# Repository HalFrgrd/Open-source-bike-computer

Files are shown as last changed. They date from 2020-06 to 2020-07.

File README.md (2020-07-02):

# Open source-bike-computer
Designs for an open source bike computer.

Similar projects:
- https://github.com/vincent290587/stravaV10
- http://opencyclingcomputer.eu/
- https://gitlab.com/PrzemoF/Open-Cycling-Computer
- https://github.com/hishizuka/pizero_bikecomputer

## BOM

<!-- ![t-call 1.3 dimensions](tcall_dimensions.png) -->
<!-- |---|---|---|---|---| -->
<!-- |**Preassembled** T-Call v1.3 TTGO ESP32 (no GPS)   | 29 x 7 x 8mm   | $16  | No  |   | -->

||**Item** | **Dimensions** | **Cost**  | **Using**  | |
|---|---|---|---|---|---|
|**Display**|
|| | | $13 | Yes  | |
|**Battery and charging**|
||3.7v Lithium Polymer 3200mAh | 50 x 75 x 7mm  | $8.50  | Yes  | |
||Receiver pad | 0.5mm thick  | $3  | Yes  | |
||Charging base  |  | $4  | Yes  | |
| **Storage** |
||16gb micro SD card | | $5  | Yes | |
|**Microcontroller and modules** |
||  ESP32 with LiPo charging  | | $5  | Yes  | |
|| nrf52840| |$5| Yes||
||  GPS module | | $5  | Yes  | |
||  SIM800L module | | $4  | Yes  | |
|| Micro SD card module  | | $1  | Yes  | |
|**Case**|
|| Glass screen protector | | $2 | Yes | |
|| 3D printed enclosure | |  | Yes | |
|| Glue | |  | Yes | |
|| 4 mounting screws | |  | Yes | |
|| 4 threaded heat inserts | |  | Yes | |
|| Rubber o-ring cabling | |  | Yes | |
| **Total** | | | | |

### Actually buying:

[LS027B7DH01](https://www.aliexpress.com/item/33020027250.html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,searchweb201602_,searchweb201603_)
The A indicates maximum of two bright pixels. 
Need an FPC 10 pin connector

## Design

3D printed

The buttons are capacitive pads. 
These pads will be a separate PCB that you can glue onto the 3D printed case.
This will be a water proof seal.
Will the capacitive pads be sensitive to rain?

Maximum target dimensions: 55 wide, 80 long, 20 high 

Need the on off control and charging port to be water proof.

### Capacitive buttons:
ESP32 has 10 capacitive-sensing GPIOs. 
So you don't need to include any extra components to use capacitive buttons
The nrf52 series also don't require any external componenents.

The capacitive pads could perhaps also go under the screen protector.
I'm guessing a screen protector wouldn't reduce the touch sensitivity that much.
This would serve as protection for the capacitive pads.

It is important to reduce the parasitic capacitance and increase the touch capacitance.
How to optimize: reduce trace length by optimizing PCB layout; reduce thickness of the overlay; enlarge electrode's area. 
Could have surface mount pins to reach PCB below.

https://github.com/espressif/esp-iot-solution/blob/master/documents/touch_pad_solution/touch_sensor_design_en.md

https://www.embedded.com/making-capacitive-touch-sensors-water-tolerant/

https://devzone.nordicsemi.com/nordic/short-range-guides/b/design-examples/posts/capacitive-touch-on-the-nrf52-series
### Firmware
https://www.youtube.com/watch?v=lQ157ftTnSs

Google maps platform has a $200 free monthly usage. Could use their route planning.

### Display
[2.42" OLED](https://www.aliexpress.com/item/32950562791.html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,searchweb201602_,searchweb201603_)
Not the best choice since they compete with sunlight.

Reflective LCD

https://www.buydisplay.com/blog/what-are-the-main-differences-between-LCD-and-OLED.html

https://www.buydisplay.com/3-4-inch-graphic-touchscreen-lcd-cog-module-240x160-single-sided-fpc
https://www.buydisplay.com/3-inch-touch-240x120-graphic-displays-lcd-serial-interface-black-on-white

https://forum.arduino.cc/index.php?topic=188040.0
https://forum.arduino.cc/index.php?topic=488097.0
https://forum.arduino.cc/index.php?topic=554754.0

Vincent's stravaV10 uses Memory LCD LS027B7DH01
https://makerdyne.com/2015/02/08/large-memory-lcd-breakout-board-details/
https://makerdyne.files.wordpress.com/2015/12/MemoryLCD_Breakout_Board_Schematic.pdf

The LS027B7DH01 with a backlight by Flex:
https://www.digikey.com/products/en?mpart=11103-06_T5&v=2004

### Wireless charging
This both for convenience and keeping the enclosure waterproof. 
Quite cheap for a whole setup. The pad inside of the computer can be very slim.

This one is small enough to be away from antennas.
https://www.mouser.co.uk/ProductDetail/PulseLarsen-Antennas/WMRR124F-2?qs=w%2Fv1CP2dgqrPY4DsgoYlEg%3D%3D

### Contactless payment
https://www.instructables.com/id/RFID-NFC-Tap-and-Go-Ring-for-Credit-Card-Payment/

Could just have a thin slot for a pay as you go card (Revolut or Monzo).Could have SMS notifications so that the bike computer knows when you have paid. 
Set up that sim with that bank card.
Could acetone the bank card to make it slimmer.

### SIM
https://lastminuteengineers.com/sim800l-gsm-module-arduino-tutorial/
I hope to be able to use the microphone pins to play pre-recorded messages.

### PCB design

Pin choice: It seems like the nrf52840 are pretty multi-purpose. For high-frequency stuff, try and avoid pins close to the antenna to avoid interference.
https://devzone.nordicsemi.com/f/nordic-q-a/52857/recommended-pin-usage

P0.0 = 0, P0.1 = 1 .... P0.31 = 31 P1.0 = 32, P1.1 = 33. 

Sharp memory schematics:
https://makerdyne.files.wordpress.com/2015/12/MemoryLCD_Breakout_Board_Schematic.pdf

One set of SPI pins per peripheral: they might work at different speeds. And I think the asynchronous aspect would mean the LCD could be prioritized.

https://github.com/DF4IAH/HFT-Core-Module

Antenna:
SIM868 is L1 band.
Glonass L1: about 1602 MHz
GPS L1: 1575.42 MHz
Beidou: 1575.42 MHz (Possibly lower: 1561.098MHz?)

https://www.antenova.com/integration-hub/antenna-selection-tool/

Drawing antennas as part of the PCB seem like a bad idea. 
They take a lot of testing.

Mouser sells the SR4L049 (both left and right versions) for about 3 dollars. SR4L034 is very similar.

The M20057 and M20047 modules combine the SAW and antenna. Power consumption is about 2ma,

M20047 cost: 4.50 gbp from mouser and at digikey
B3913 cost: 1.62gbp 
SR4L034 cost: 1.44
LNA?:

I'm pretty sure it needs an LNA. So I'm going with 
https://www.u-blox.com/sites/default/files/NEO-8Q-NEO-M8-FW3_HIM_%28UBX-15029985%29.pdf

[Picking a saw filter from Mouser](https://www.mouser.com/pdfdocs/HowToChoosetheOptimalSAWFilter.pdf)

SAW filter: You want something in the middle of the frequencies, so 1588ish and that has a wide enough bandwidth to capture the signals.
Two come up: B3913 and B3413. The B4310 is used in the HFT-Core-Module.
B4310 is from 2015. The B3913 and B3413 are very similar but the B3413 is newer and has improved electrostatic discharge (ESD) robustness. [Qualcomm RF360 website SAW filters for GNSS](https://rffe.qualcomm.com/product/search/automotive/Filters%20for%20GNSS). B4310 doesn't have Beidou next to it on the website. 
I can't find the B3413 in stock, so I'm using the B3913 in stock at digi key.

#### Questions
- The wireless charging setup.
- Battery level indicator.
- Why polarized capacitor in decoupling?
- RF SYNC
- What about low noise ammplifer LNA?

### Case
**Two pcb design**
Have a pcb at the top. 
This has a cut out for the screen.
This top pcb has capacitive buttons.
On the underside of this top pcb, are an on off switch and maybe the usb port. Also could have pressure, temperature, humidity sensor as it should be on the outside? The traces are the link between the outside and the inside.
The 3D printed bottom port of the case could just be unibody.
There would be pcb to pcb connectors.
The top pcb would have surface mounted pins on the underside.
The bottom pcb would have the female connectors.
When you align the pins, the top pcb drops into the bottom one.
[These are pin and socket](https://blog.samtec.com/post/custom-connectors-for-stacking-pcbs/)
There would be o-rings around each of the mounting screws and o-ring cord going around the perimeter.

The two PCBs could fit together inside the 100x100mm size.

Could this extend the ground plane?:
https://blog.antenova.com/how-well-can-an-embedded-antenna-perform-on-a-tiny-pcb

Threaded PCB inserts could provide a flush mounting style.

Connections between plates:
- Ground
- VCC
- Battery switch
- Data+
- Data -
- 5x buttons
- Temperature, pressure, humidity sensor.

Connectors: https://www.samtec.com/products/ftsh

Pins:FTSH-104-01-F-DV
Connector: CLP-104-02-F-D

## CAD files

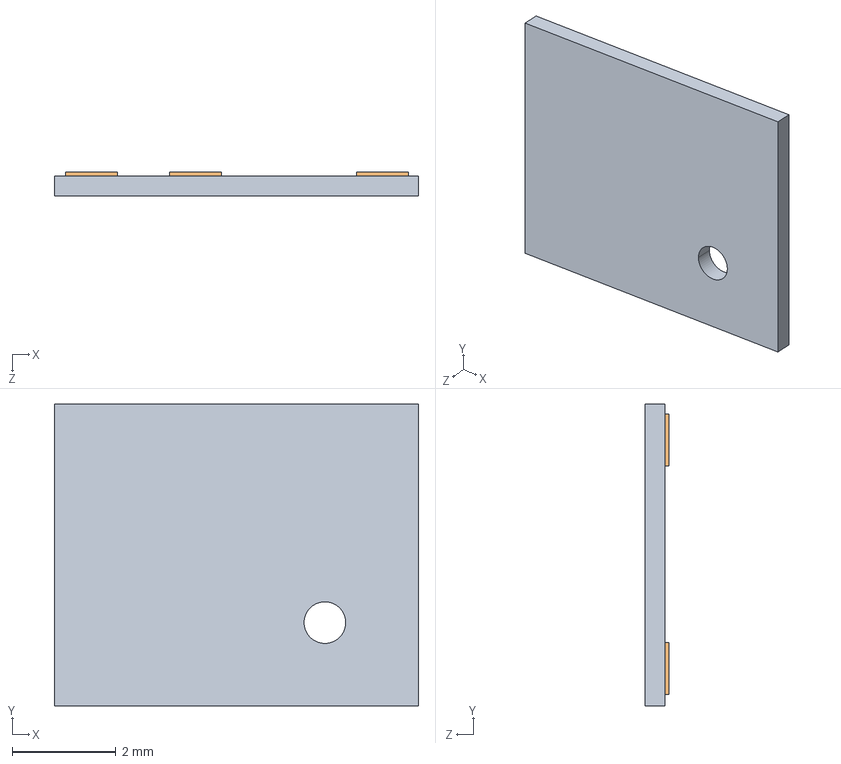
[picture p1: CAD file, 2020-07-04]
pcb/open_bike_comp3D/SR4G008_Sinica.STEP
7.00 x 5.80 x 0.469 mm
ant part with text and hole
pads

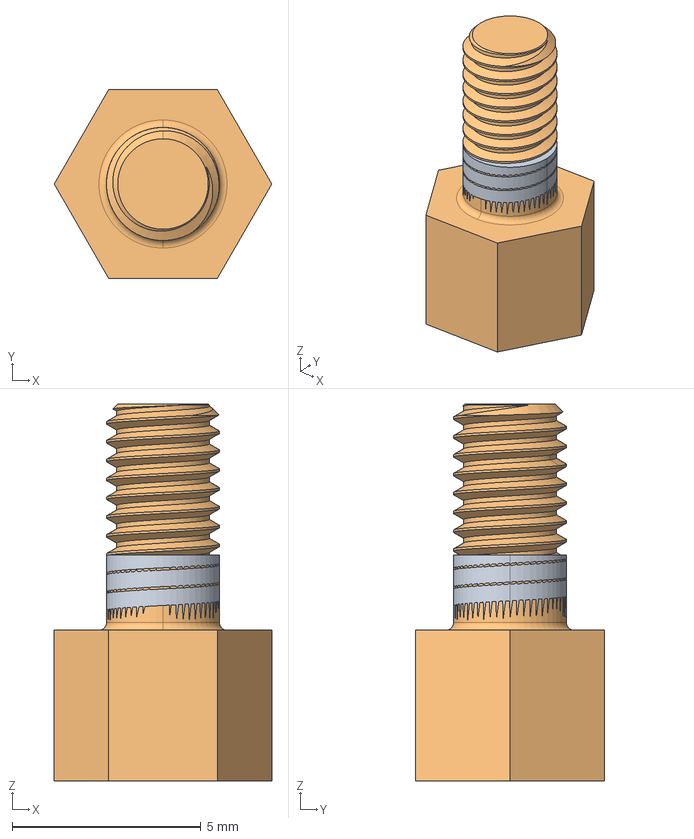
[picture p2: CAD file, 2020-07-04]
pcb/open_bike_comp3D/r30-3000402.stp
5.77 x 5.00 x 10.0 mm

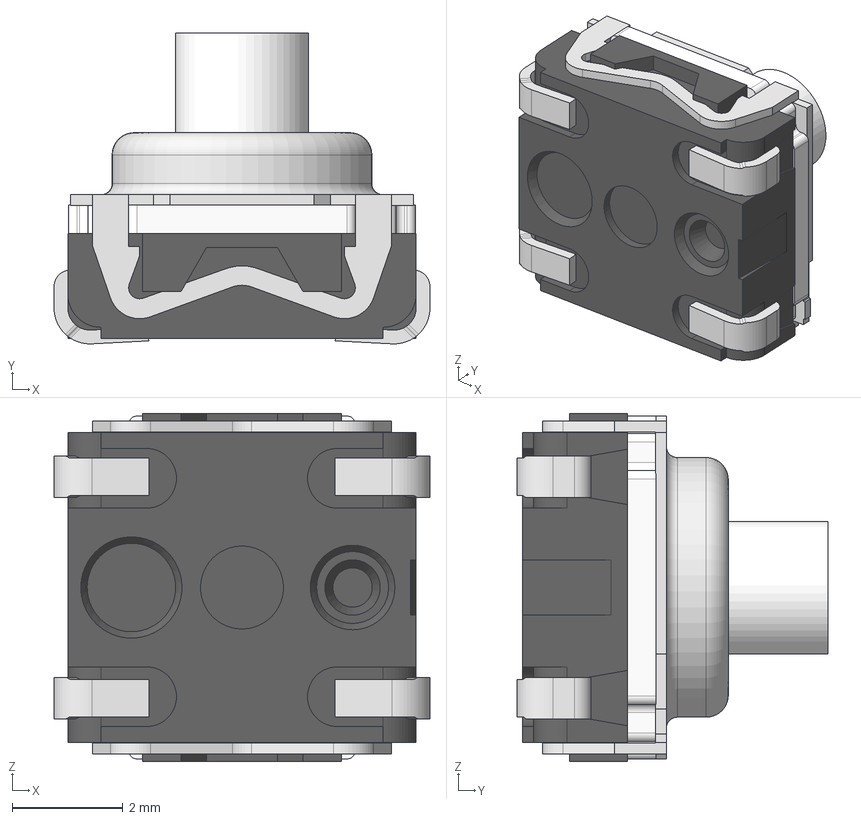
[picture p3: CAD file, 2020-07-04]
pcb/open_bike_comp3D/KSC521JROHS.stp
6.80 x 5.62 x 6.30 mm
_KSC5_body
_KSC5_button
_KSC5_cover
_KSC51J_pin x 4

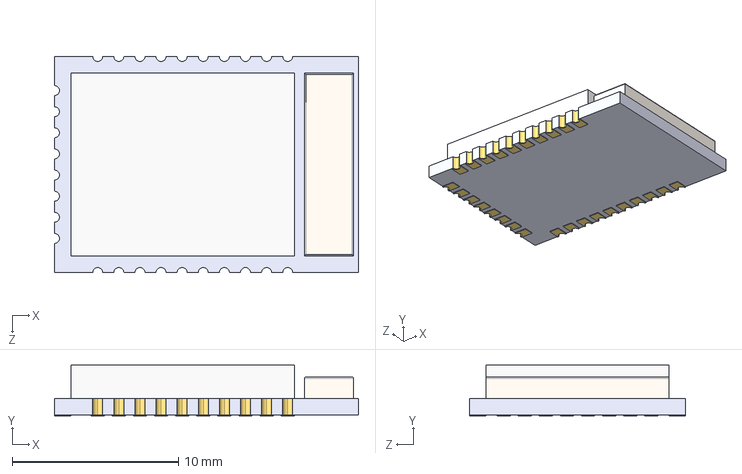
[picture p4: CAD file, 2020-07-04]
pcb/open_bike_comp3D/E73-2G4M08S1C.step
18.3 x 3.05 x 13.0 mm

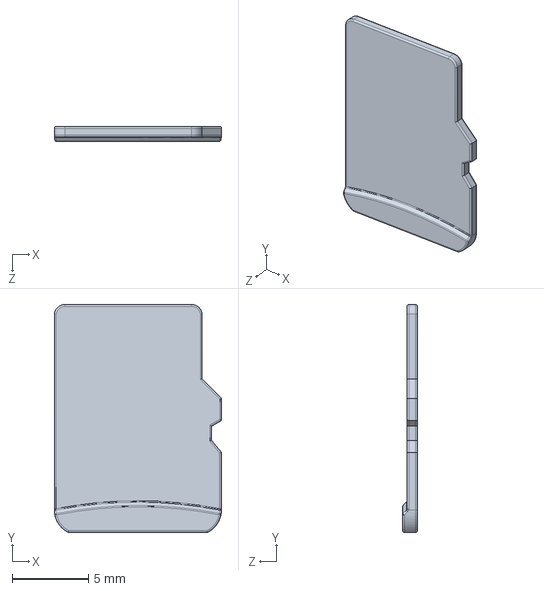
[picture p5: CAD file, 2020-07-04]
pcb/open_bike_comp3D/Micro SD Card.STEP
11.0 x 15.0 x 1.00 mm

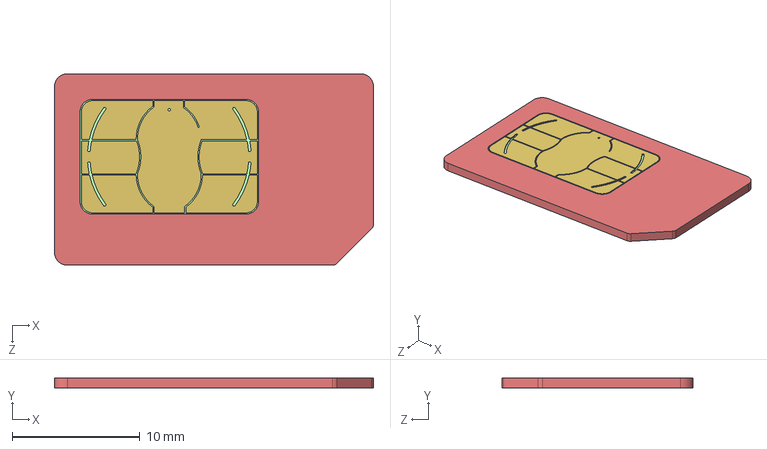
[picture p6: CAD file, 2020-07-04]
pcb/open_bike_comp3D/SIM card.STEP
25.0 x 0.8 x 15.0 mm

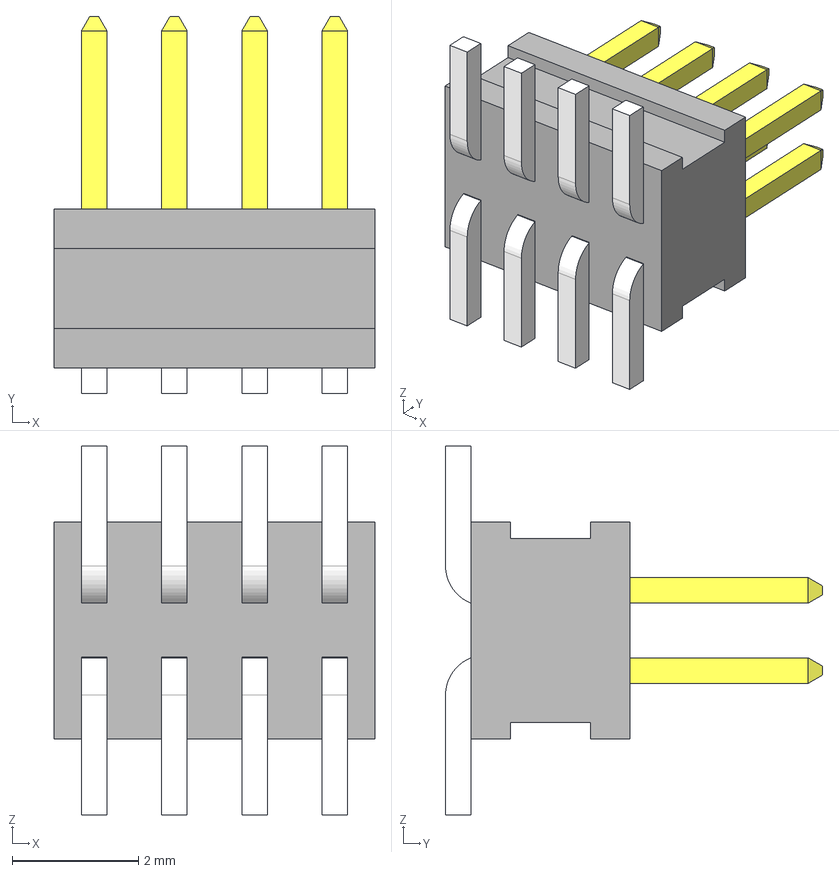
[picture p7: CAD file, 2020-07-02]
pcb/open_bike_comp3D/FTSH-104-01-F-DV.stp
5.08 x 5.97 x 5.84 mm
_FTSH-104-01-F-DV_body
_FTSH-104-01-F-DV_pins1
_FTSH-104-01-F-DV_pins2

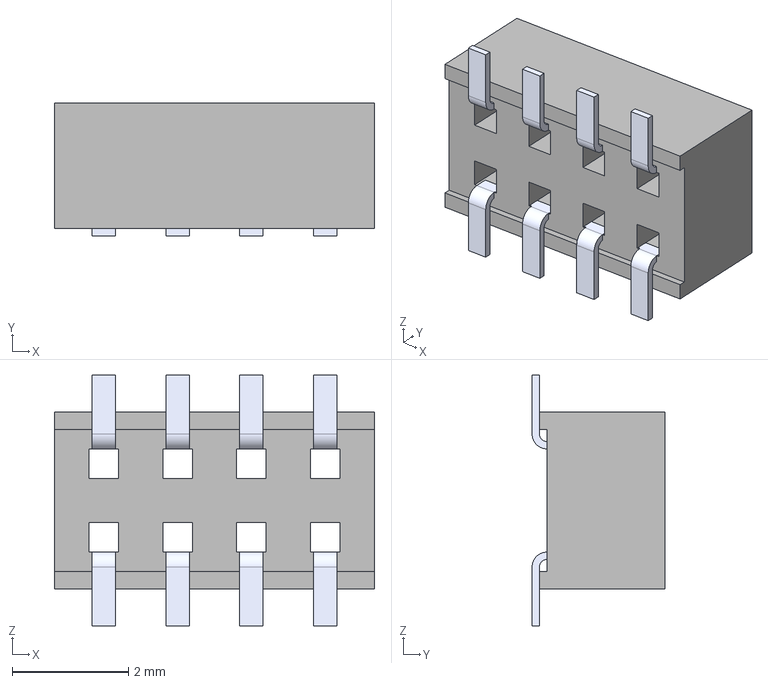
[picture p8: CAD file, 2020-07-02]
pcb/open_bike_comp3D/CLP-104-02-F-D.stp
5.51 x 2.29 x 4.32 mm
_CLP-104-2-F-D_terminal
_C-106-22-104_Pin x 2

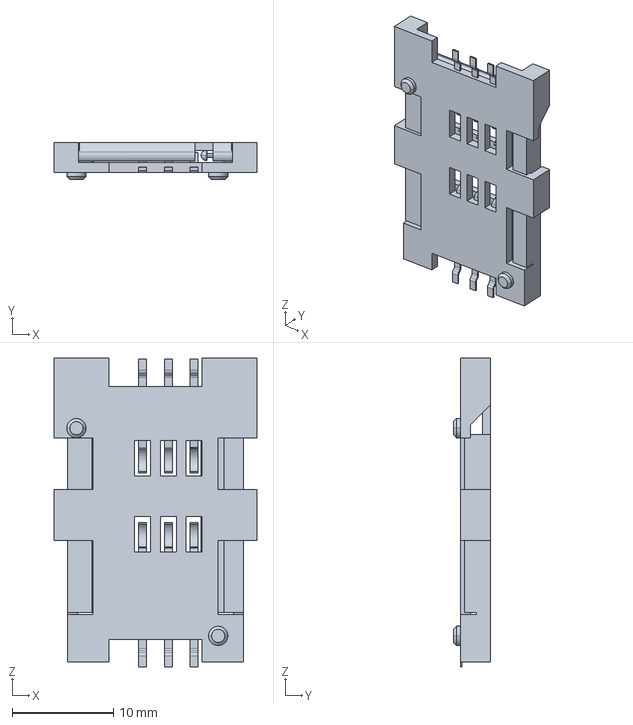
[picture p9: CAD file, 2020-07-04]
pcb/open_bike_comp3D/7312S0815X29LFC_sim_holder.stp
20.0 x 3.70 x 30.5 mm

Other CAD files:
case_design/case_design.FCStd

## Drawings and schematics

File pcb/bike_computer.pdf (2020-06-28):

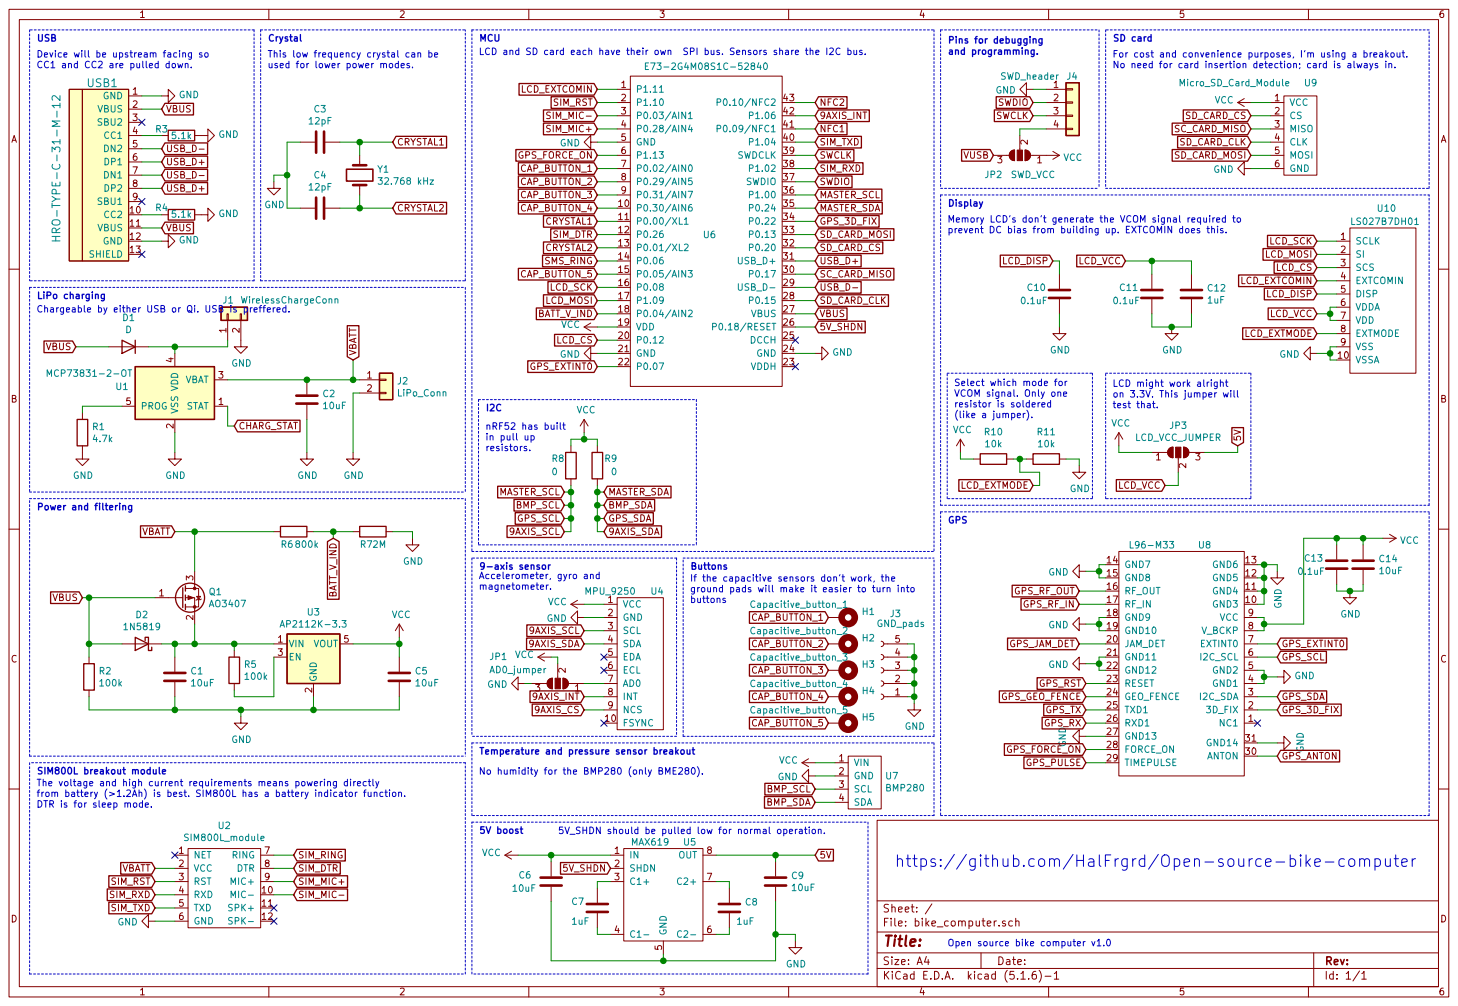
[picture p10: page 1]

CC1 and CC2 are pulled down.

This low frequency crystal can be
used for lower power modes.

For cost and convenience purposes, I'm using a breakout.
No need for card insertion detection; card is always in.

Display Memory LCD's don't generate the VCOM signal required to

prevent DC bias from building up. EXTCOMIN does this.

LiPo charging

Select which mode for VCOM signal. Only one resistor is soldered (like a jumper).

LCD might work alright

on 3.3V. This jumper will test that. 9-axis sensor
nRF52 has built
in pull up resistors. No humidity for the BMP280 (only BME280).

If the capacitive sensors don't work, the 5

Temperature and pressure sensor breakout

The voltage and high current requirements means powering directly
from battery (>1.2Ah) is best. SIM800L has a battery indicator function.
DTR is for sleep mode.

5V_SHDN should be pulled low for normal operation.

https://github.com/HalFrgrd/Open-source-bike-computer

Open source bike computer v1.0

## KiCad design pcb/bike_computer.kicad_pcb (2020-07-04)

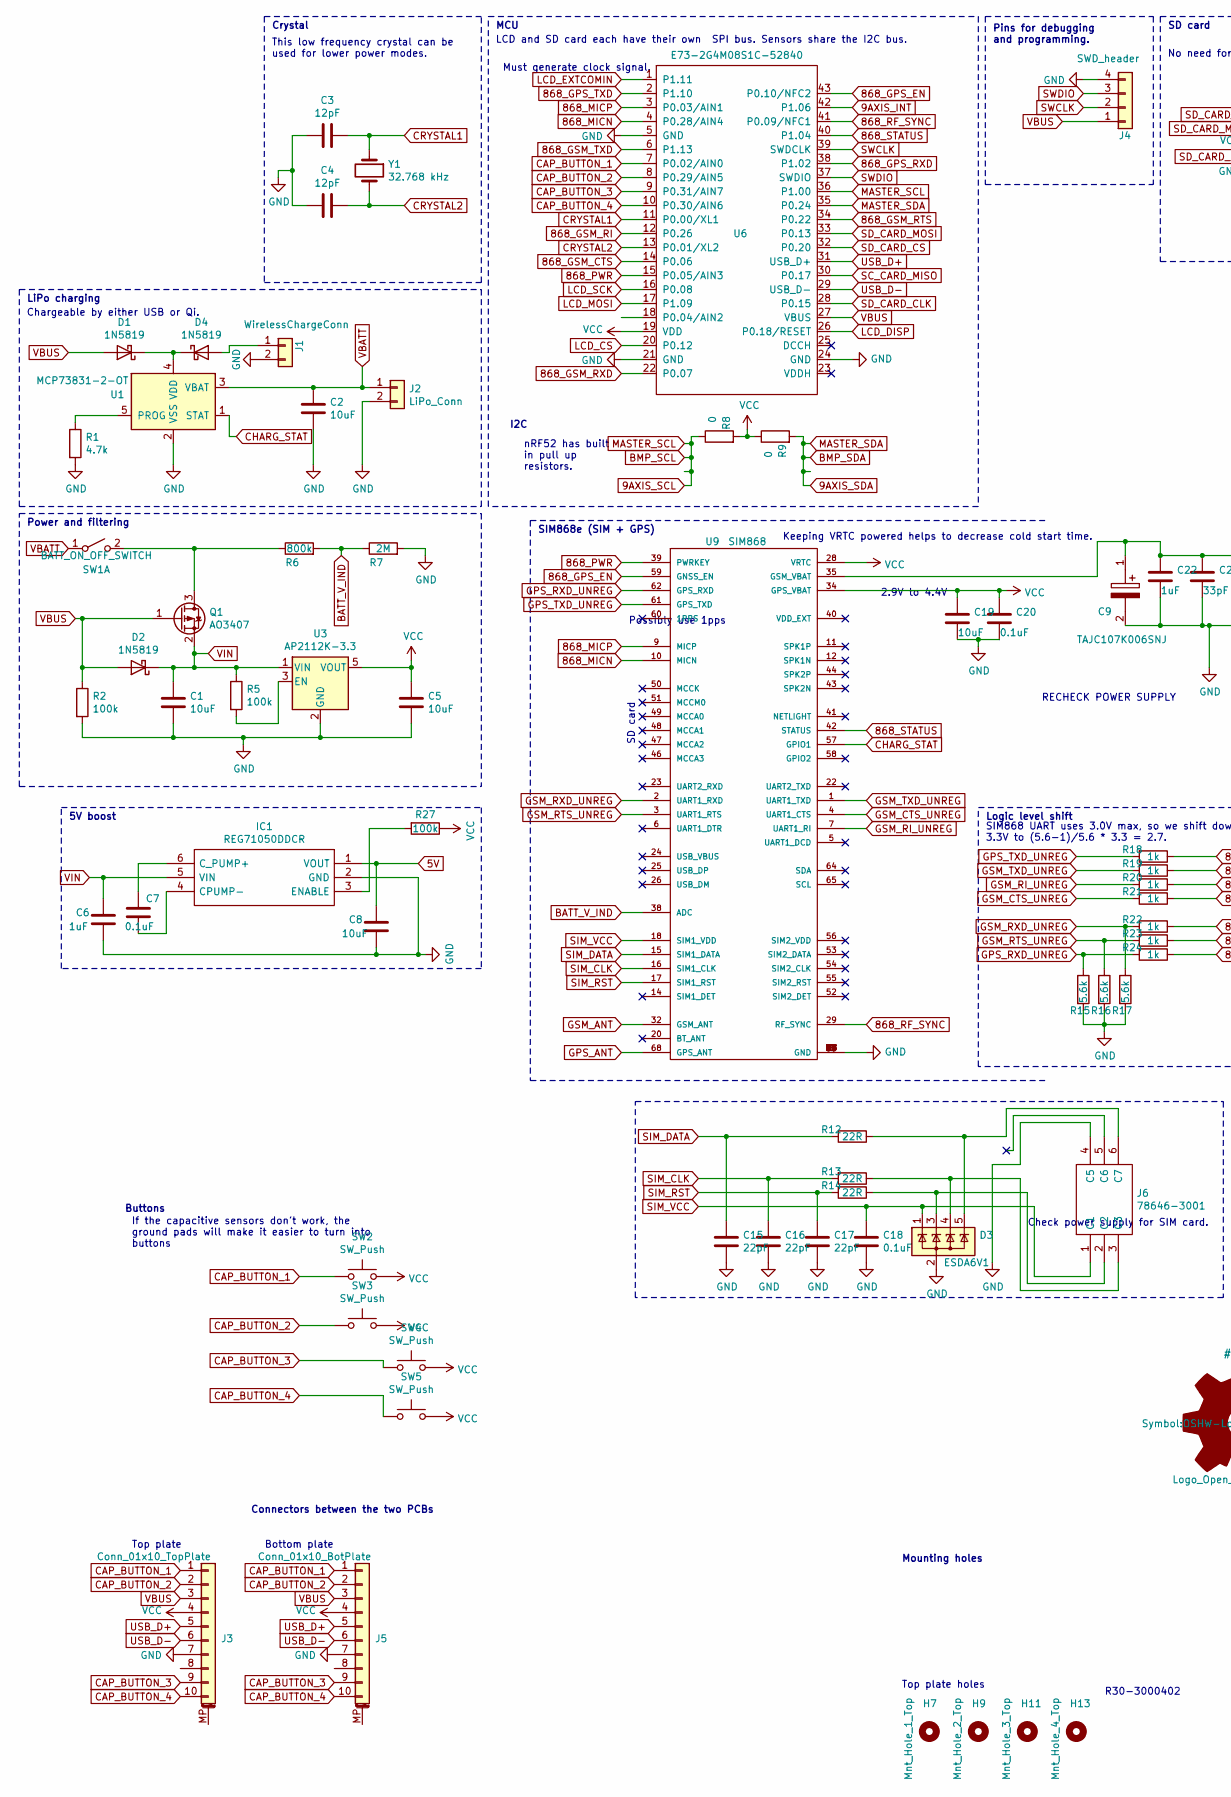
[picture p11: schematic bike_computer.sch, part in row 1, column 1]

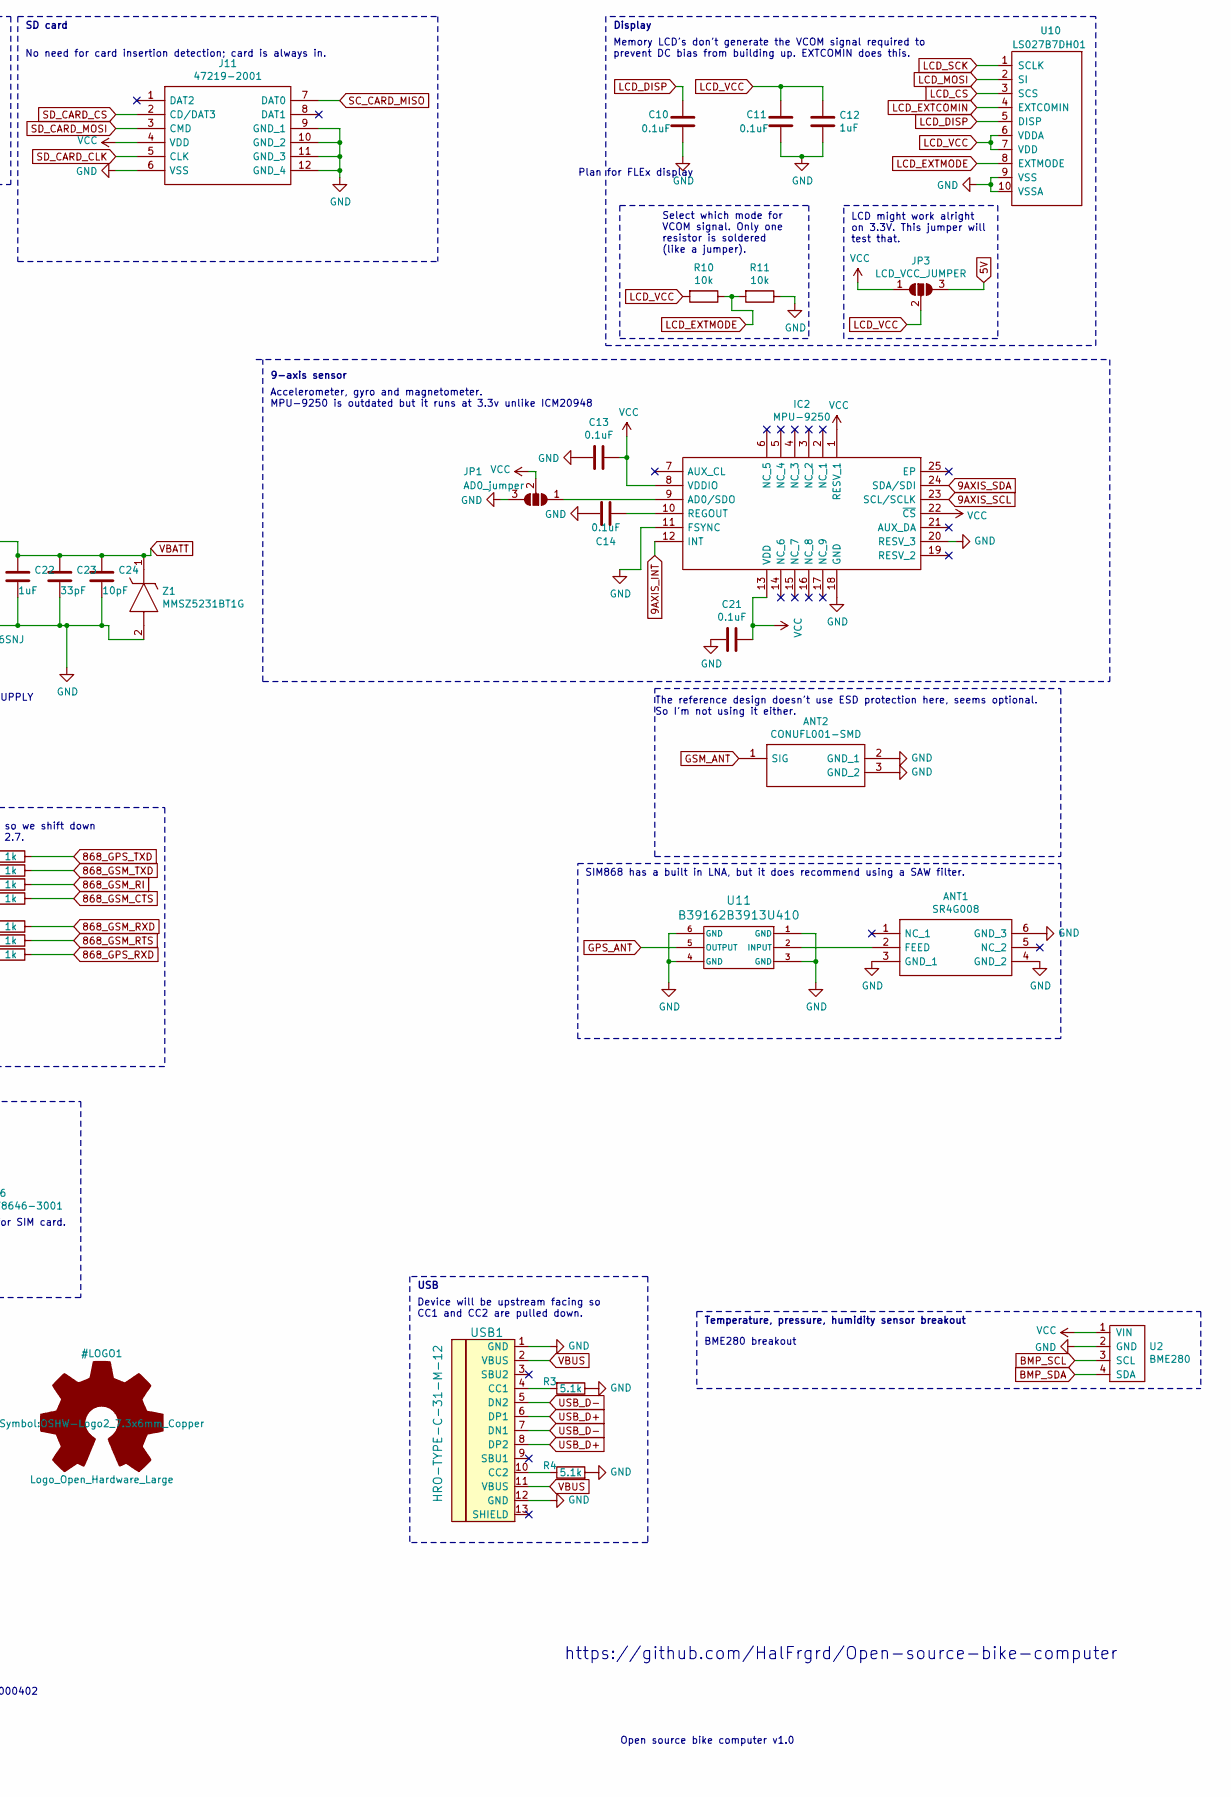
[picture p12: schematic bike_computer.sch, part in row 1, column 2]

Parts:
ANT1: SR4G008; Mouser Part Number 237-SR4G008
ANT2: CONUFL001-SMD; Mouser Part Number 712-CONUFL001-SMD
C1, C2, C5, C8, C19: 10uF; 1206_0603_hand_solder
C3, C4: 12pF; 1206_0603_hand_solder
C6, C12, C22: 1uF; 1206_0603_hand_solder
C7, C10, C11, C13, C14, C18, C20, C21: 0.1uF; 1206_0603_hand_solder
C9: TAJC107K006SNJ; CAPPM6032X280N; Mouser Part Number 581-TAJC107K006SNJ
C15, C16, C17: 22pF; 1206_0603_hand_solder
C23: 33pF; 1206_0603_hand_solder
C24: 10pF; 1206_0603_hand_solder
D1, D2, D4: 1N5819; D_SOD-123
D3: ESDA6V1; SOT95P280X145-6N
H7: Mnt_Hole_1_Top; R303000402
H9: Mnt_Hole_2_Top; R303000402
H11: Mnt_Hole_3_Top; R303000402
H13: Mnt_Hole_4_Top; R303000402
IC1: REG71050DDCR; SOT95P280X110-6N; Mouser Part Number 595-REG71050DDCR
IC2: MPU-9250; QFN40P300X300X105-25N-D; Mouser Part Number 410-MPU-9250
J1: WirelessChargeConn; PinHeader_1x02_P1.27mm_Vertical
J2: LiPo_Conn; PinHeader_1x02_P1.27mm_Vertical
J3: Conn_01x10_TopPlate; 10_smd_connector
J4: SWD_header; PinHeader_1x04_P2.54mm_Vertical
J5: Conn_01x10_BotPlate; PinHeader_1x10_P2.54mm_Vertical
J6: 78646-3001; Mouser Part Number 538-78646-3001
J11: 47219-2001; 472192001; Mouser Part Number 538-47219-2001
JP1: AD0_jumper; SolderJumper-3_P1.3mm_Open_RoundedPad1.0x1.5mm
JP3: LCD_VCC_JUMPER; SolderJumper-3_P1.3mm_Open_RoundedPad1.0x1.5mm
Q1: AO3407; SOT-23
R1: 4.7k; 1206_0603_hand_solder
R2, R5, R27: 100k; 1206_0603_hand_solder
R3, R4: 5.1k; 1206_0603_hand_solder
R6: 800k; 1206_0603_hand_solder
R7: 2M; 1206_0603_hand_solder
R8, R9: 0; 1206_0603_hand_solder
R10, R11: 10k; 1206_0603_hand_solder
R12, R13, R14: 22R; 1206_0603_hand_solder
R15, R16, R17: 5.6k; 1206_0603_hand_solder
R18, R19, R20, R21, R22, R23, R24: 1k; 1206_0603_hand_solder
SW1: BATT_ON_OFF_SWITCH; switch_MSK-12C02_smd
SW2, SW3, SW4, SW5: SW_Push; KSC521JROHS_with_pad
U1: MCP73831-2-OT; SOT-23-5
U2: BME280
U3: AP2112K-3.3; SOT-23-5
U6: E73-2G4M08S1C-52840
U9: SIM868; XCVR_SIM868
U10: LS027B7DH01; TE_1-1734839-0_1x10-1MP_P0.5mm_Horizontal
U11: B39162B3913U410
USB1: HRO-TYPE-C-31-M-12
Y1: 32.768 kHz; Crystal_DS26_D2.0mm_L6.0mm_Horizontal
Z1: MMSZ5231BT1G; SOD3716X135N; Mouser Part Number 863-MMSZ5231BT1G

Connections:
5V: C8.1, IC1.1 (VOUT), JP3.3 (B)
9AXIS_INT: IC2.12 (INT), U6.42 (P1.06)
9AXIS_SCL: IC2.23 (SCL/SCLK), R8.1, U2.3 (SCL), U6.36 (P1.00)
9AXIS_SDA: IC2.24 (SDA/SDI), R9.2, U2.4 (SDA), U6.35 (P0.24)
868_GPS_EN: U6.43 (P0.10/NFC2), U9.59 (GNSS_EN)
868_GPS_RXD: R24.1, U6.38 (P1.02)
868_GPS_TXD: R18.1, U6.2 (P1.10)
868_GSM_CTS: R21.1, U6.14 (P0.06)
868_GSM_RI: R20.1, U6.12 (P0.26)
868_GSM_RTS: R23.1, U6.34 (P0.22)
868_GSM_RXD: R22.1, U6.22 (P0.07)
868_GSM_TXD: R19.1, U6.6 (P1.13)
868_MICN: U6.4 (P0.28/AIN4), U9.10 (MICN)
868_MICP: U6.3 (P0.03/AIN1), U9.9 (MICP)
868_PWR: U6.15 (P0.05/AIN3), U9.39 (PWRKEY)
868_RF_SYNC: U6.41 (P0.09/NFC1), U9.29 (RF_SYNC)
868_STATUS: U6.40 (P1.04), U9.42 (STATUS)
BATT_V_IND: R6.2, R7.1, U9.38 (ADC)
CAP_BUTTON_1: J3.1, J5.1, SW2.1, U6.7 (P0.02/AIN0)
CAP_BUTTON_2: J3.2, J5.2, SW3.1, U6.8 (P0.29/AIN5)
CAP_BUTTON_3: J3.9, J5.9, SW4.1, U6.9 (P0.31/AIN7)
CAP_BUTTON_4: J3.10, J5.10, SW5.1, U6.10 (P0.30/AIN6)
CHARG_STAT: U1.1 (STAT), U9.57 (GPIO1)
CRYSTAL1: C3.1, U6.11 (P0.00/XL1), Y1.1
CRYSTAL2: C4.1, U6.13 (P0.01/XL2), Y1.2
GND: ANT1.3 (GND_1), ANT1.4 (GND_2), ANT1.6 (GND_3), ANT2.2 (GND_1), ANT2.3 (GND_2), C1.2, C2.2, C3.2, C4.2, C5.2, C6.2, C8.2, C9.2, C10.2, C11.2, C12.2, C13.2, C14.1, C15.2, C16.2, C17.2, C18.2, C19.2, C20.2, C21.2, C22.2, C23.2, C24.2, D3.2 (A), IC1.2 (GND), IC2.11 (FSYNC), IC2.18 (GND), IC2.20 (RESV_3), J1.2, J2.2, J3.7, J4.4, J5.7, J6.4 (C5), J11.6 (VSS), J11.9 (GND_1), J11.10 (GND_2), J11.11 (GND_3), J11.12 (GND_4), JP1.3 (B), R1.2, R2.2, R3.1, R4.2, R7.2, R11.1, R15.2, R16.2, R17.2, U1.2 (VSS), U2.2 (GND), U3.2 (GND), U6.5 (GND), U6.21 (GND), U6.24 (GND), U9.8 (GND), U9.13 (GND), U9.19 (GND), U9.21 (GND), U9.27 (GND), U9.30 (GND), U9.31 (GND), U9.33 (GND), U9.36 (GND), U9.37 (GND), U9.45 (GND), U9.63 (GND), U9.66 (GND), U9.67 (GND), U9.69 (GND), U9.70 (GND), U9.71 (GND), U9.72 (GND), U9.73 (GND), U9.74 (GND), U9.75 (GND), U9.76 (GND), U9.77 (GND), U10.9 (VSS), U10.10 (VSSA), U11.1 (GND), U11.3 (GND), U11.4 (GND), U11.6 (GND), USB1.1 (GND), USB1.12 (GND), Z1.2
GPS_ANT: U9.68 (GPS_ANT), U11.5 (OUTPUT)
GPS_RXD_UNREG: R15.1, R24.2, U9.62 (GPS_RXD)
GPS_TXD_UNREG: R18.2, U9.61 (GPS_TXD)
GSM_ANT: ANT2.1 (SIG), U9.32 (GSM_ANT)
GSM_CTS_UNREG: R21.2, U9.4 (UART1_CTS)
GSM_RI_UNREG: R20.2, U9.7 (UART1_RI)
GSM_RTS_UNREG: R16.1, R23.2, U9.3 (UART1_RTS)
GSM_RXD_UNREG: R17.1, R22.2, U9.2 (UART1_RXD)
GSM_TXD_UNREG: R19.2, U9.1 (UART1_TXD)
LCD_CS: U6.20 (P0.12), U10.3 (SCS)
LCD_DISP: C10.1, U6.26 (P0.18/RESET), U10.5 (DISP)
LCD_EXTCOMIN: U6.1 (P1.11), U10.4 (EXTCOMIN)
LCD_EXTMODE: R10.1, R11.2, U10.8 (EXTMODE)
LCD_MOSI: U6.17 (P1.09), U10.2 (SI)
LCD_SCK: U6.16 (P0.08), U10.1 (SCLK)
LCD_VCC: C11.1, C12.1, JP3.2 (C), R10.2, U10.6 (VDDA), U10.7 (VDD)
unnamed: ANT1.2 (FEED), U11.2 (INPUT)
unnamed: C7.1, IC1.6 (C_PUMP+)
unnamed: C7.2, IC1.4 (CPUMP-)
unnamed: C14.2, IC2.10 (REGOUT)
unnamed: D1.1 (K), D4.1 (K), U1.4 (VDD)
unnamed: D3.3 (K), J6.2 (C2), R14.1
unnamed: D3.4 (K), J6.3 (C3), R13.1
unnamed: D3.5 (K), J6.6 (C7), R12.1
unnamed: D4.2 (A), J1.1
unnamed: IC1.3 (ENABLE), R27.2
unnamed: IC2.9 (AD0/SDO), JP1.1 (A)
unnamed: Q1.3 (D), R6.1, SW1.2 (B)
unnamed: R1.1, U1.5 (PROG)
unnamed: R3.2, USB1.4 (CC1)
unnamed: R4.1, USB1.10 (CC2)
unnamed: R5.2, U3.3 (EN)
SC_CARD_MISO: J11.7 (DAT0), U6.30 (P0.17)
SD_CARD_CLK: J11.5 (CLK), U6.28 (P0.15)
SD_CARD_CS: J11.2 (CD/DAT3), U6.32 (P0.20)
SD_CARD_MOSI: J11.3 (CMD), U6.33 (P0.13)
SIM_CLK: C16.1, R13.2, U9.16 (SIM1_CLK)
SIM_DATA: C15.1, R12.2, U9.15 (SIM1_DATA)
SIM_RST: C17.1, R14.2, U9.17 (SIM1_RST)
SIM_VCC: C18.1, D3.1 (K), J6.1 (C1), U9.18 (SIM1_VDD)
SWCLK: J4.2, U6.39 (SWDCLK)
SWDIO: J4.3, U6.37 (SWDIO)
USB_D+: J3.5, J5.5, U6.31 (USB_D+), USB1.6 (DP1), USB1.8 (DP2)
USB_D-: J3.6, J5.6, U6.29 (USB_D-), USB1.5 (DN2), USB1.7 (DN1)
VBATT: C2.1, C9.1, C22.1, C23.1, C24.1, J2.1, SW1.1 (A), U1.3 (VBAT), U9.35 (GSM_VBAT), Z1.1
VBUS: D1.2 (A), D2.2 (A), J3.3, J4.1, J5.3, Q1.1 (G), R2.1, U6.27 (VBUS), USB1.2 (VBUS), USB1.11 (VBUS)
VCC: C5.1, C13.1, C19.1, C20.1, C21.1, IC2.1 (RESV_1), IC2.8 (VDDIO), IC2.13 (VDD), IC2.22 (~CS), J3.4, J5.4, J11.4 (VDD), JP1.2 (C), JP3.1 (A), R8.2, R9.1, R27.1, SW2.2, SW3.2, SW4.2, SW5.2, U2.1 (VIN), U3.5 (VOUT), U6.19 (VDD), U9.28 (VRTC), U9.34 (GPS_VBAT)
VIN: C1.1, C6.1, D2.1 (K), IC1.5 (VIN), Q1.2 (S), R5.1, U3.1 (VIN)

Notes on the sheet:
MCU
Power and filtering
LiPo charging
USB
SD card
Memory LCD's don't generate the VCOM signal required to prevent DC bias from building up. EXTCOMIN does this.
Display
Select which mode for VCOM signal. Only one resistor is soldered (like a jumper).
Device will be upstream facing so CC1 and CC2 are pulled down.
This low frequency crystal can be used for lower power modes.
Crystal
LCD might work alright on 3.3V. This jumper will test that.
No need for card insertion detection; card is always in.
9-axis sensor
Pins for debugging and programming.
BME280 breakout
I2C
nRF52 has built in pull up resistors.
Temperature, pressure, humidity sensor breakout
Buttons
5V boost
https://github.com/HalFrgrd/Open-source-bike-computer
Open source bike computer v1.0
LCD and SD card each have their own SPI bus. Sensors share the I2C bus.
If the capacitive sensors don't work, the ground pads will make it easier to turn into buttons
Accelerometer, gyro and magnetometer. MPU-9250 is outdated but it runs at 3.3v unlike ICM20948
Chargeable by either USB or Qi.
SIM868e (SIM + GPS)
Keeping VRTC powered helps to decrease cold start time.
SD card
Possibly use 1pps
Check power supply for SIM card.
SIM868 UART uses 3.0V max, so we shift down 3.3V to (5.6-1)/5.6 * 3.3 = 2.7.
Logic level shift
Must generate clock signal.
Plan for FLEx display
SIM868 has a built in LNA, but it does recommend using a SAW filter.
2.9V to 4.4V
RECHECK POWER SUPPLY
Connectors between the two PCBs

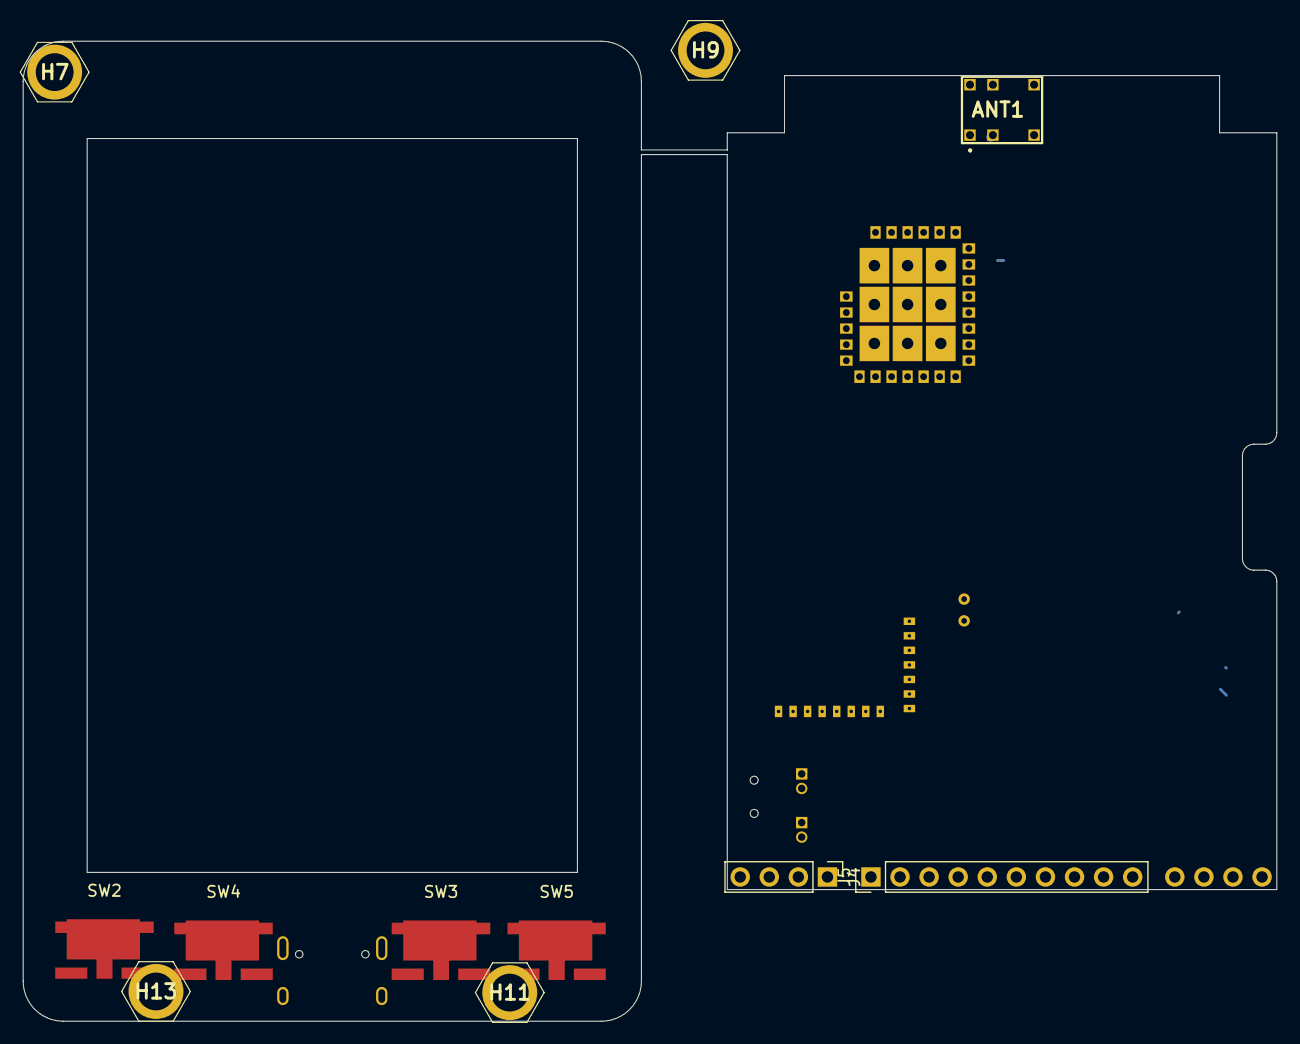
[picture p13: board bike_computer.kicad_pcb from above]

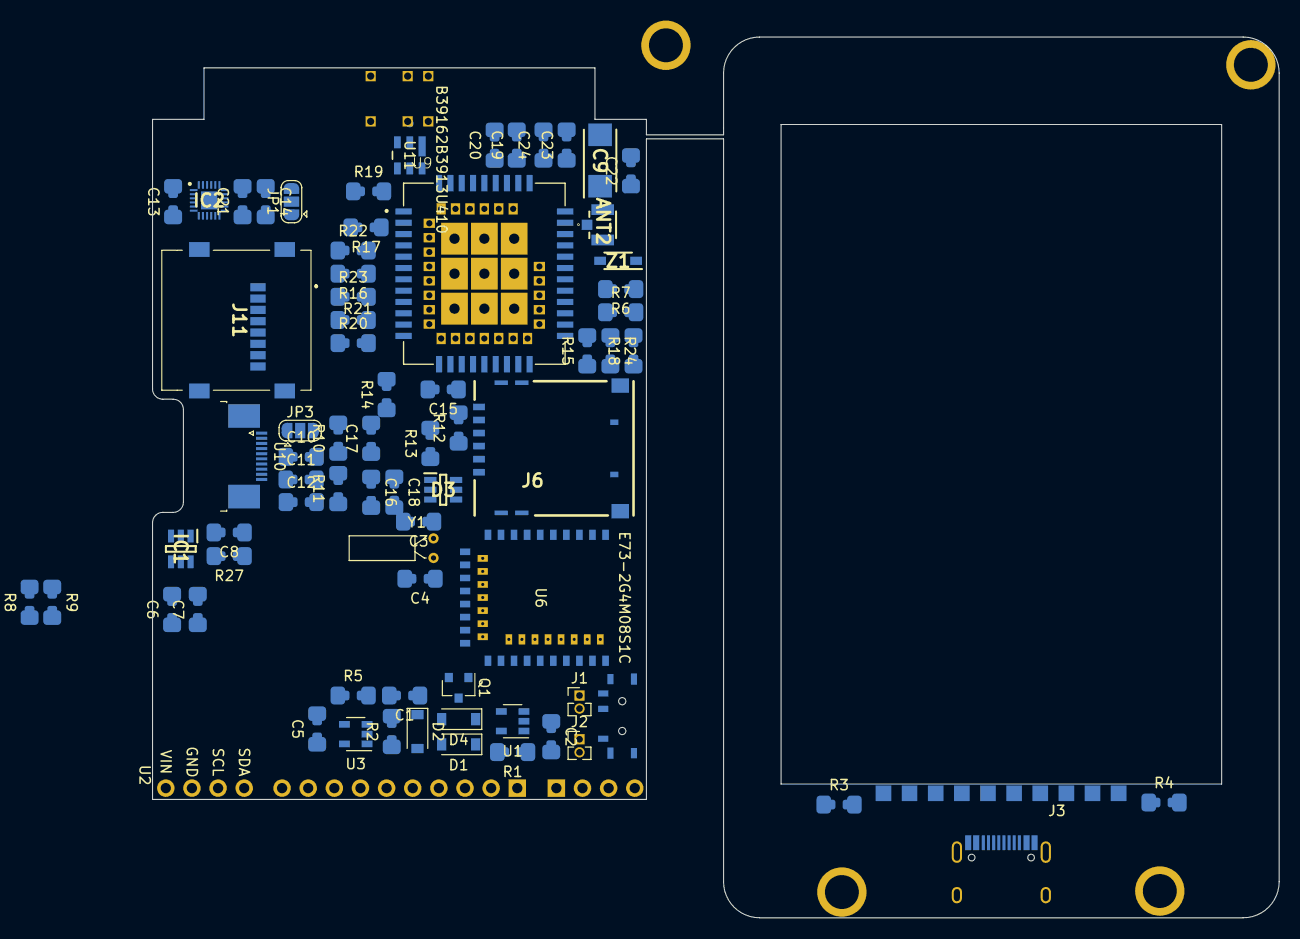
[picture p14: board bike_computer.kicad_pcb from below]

Board: 2 copper layers, 109.5 x 85.6 mm, 86 parts (75 on the bottom side), 74 nets.

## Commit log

2020-06-28 Working on a pcb
    [bike_computer.kicad_pcb, bike_computer.sch]
2020-06-28 Working on schematic
    [bike_computer.sch]
2020-06-30 worked on schematic
    [bike_computer.sch]
2020-06-30 Assigning footprints
    [bike_computer.sch]
2020-07-02 Sorting out 2 plate design
    [CLP-104-02-F-D.stp, FTSH-104-01-F-DV.stp, bike_computer.kicad_pcb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]
2020-07-04 Sorted main layout
    [7312S0815X29LFC_sim_holder.stp, E73-2G4M08S1C.step, KSC521JROHS.stp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]

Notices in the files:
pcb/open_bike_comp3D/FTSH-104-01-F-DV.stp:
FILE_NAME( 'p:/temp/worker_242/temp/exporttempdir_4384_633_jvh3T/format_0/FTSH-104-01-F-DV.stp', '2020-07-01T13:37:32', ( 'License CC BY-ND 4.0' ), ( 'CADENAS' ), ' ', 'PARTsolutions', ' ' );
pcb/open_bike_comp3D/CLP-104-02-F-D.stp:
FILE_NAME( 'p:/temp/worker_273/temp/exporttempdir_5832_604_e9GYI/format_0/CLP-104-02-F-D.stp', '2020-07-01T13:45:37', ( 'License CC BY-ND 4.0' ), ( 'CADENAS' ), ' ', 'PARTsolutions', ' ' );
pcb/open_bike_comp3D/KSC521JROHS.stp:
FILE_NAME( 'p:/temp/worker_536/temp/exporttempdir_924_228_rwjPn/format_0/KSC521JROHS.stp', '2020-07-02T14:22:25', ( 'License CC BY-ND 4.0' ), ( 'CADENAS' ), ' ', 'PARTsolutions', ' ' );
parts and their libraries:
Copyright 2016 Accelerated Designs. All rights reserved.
